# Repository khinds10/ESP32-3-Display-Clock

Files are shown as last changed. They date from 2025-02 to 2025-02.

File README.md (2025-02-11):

# ESP32 Time and Temperature Display

This project uses an ESP32 microcontroller to display the current time and temperatures on three TM1637 displays. The first display shows the current time in 12-hour format with a blinking colon and PM indicator. The second display shows the indoor temperature from a DHT22 sensor. The third display shows the outdoor temperature fetched from an online weather API.

Using openweather API - https://openweathermap.org/api/one-call-3

## Hardware Setup

### Components Required

- 1 x ESP32 Development Board
- 3 x TM1637 4-Digit 7-Segment Displays
- 1 x DHT22 Temperature and Humidity Sensor
- Jumper wires
- 5mm Tinted Plexiglas

### Wiring Diagram

#### TM1637 Displays

- **Display 1 (Time)**
  - CLK1: GPIO 22
  - DIO1: GPIO 23

- **Display 2 (Indoor Temperature)**
  - CLK2: GPIO 19
  - DIO2: GPIO 21

- **Display 3 (Outdoor Temperature)**
  - CLK3: GPIO 32
  - DIO3: GPIO 25

#### DHT22 Sensor

- VCC: 3.3V or 5V
- GND: Ground
- Data: GPIO 18

### Notes

- Ensure all components share a common ground with the ESP32.

## Software Setup

### Prerequisites

- [PlatformIO](https://platformio.org/) installed on your development environment.
- An internet connection for the ESP32 to fetch weather data.

### Check out the Git Repository
https://github.com/khinds10/ESP32-3-Display-Clock
This includes the STL files for 3D printing as well as the code to upload to the ESP32 to get it to run.

### Configuration

1. **Copy Configuration File**

   Copy `src/config_shadow.h` to `src/config.h` and update the configuration values:

   ```bash
   cp src/config_shadow.h src/config.h
   ```

2. **Edit `config.h`**

   Update the following configuration values in `src/config.h`:

   #### Time Settings
   ```cpp
   #define TIME_ZONE -5        // Your timezone offset from UTC (e.g., -5 for EST)
   #define DST_OFFSET 1        // Daylight Saving Time offset (1 for DST, 0 for no DST)
   ```

   #### Display Brightness (0-7)
   ```cpp
   #define TIME_DISPLAY_BRIGHTNESS 3     // Brightness for time display
   #define INSIDE_TEMP_BRIGHTNESS 1      // Brightness for indoor temperature display
   #define OUTSIDE_TEMP_BRIGHTNESS 1     // Brightness for outdoor temperature display
   ```

   #### Temperature Calibration
   ```cpp
   #define TEMP_OFFSET 0.0     // Temperature offset in degrees (adjust if sensor readings need calibration)
   ```

   #### WiFi Settings
   ```cpp
   const char* ssid = "Your_WiFi_SSID";
   const char* password = "Your_WiFi_Password";
   ```

   #### Data Services Configuration
   ```cpp
   // DataHub API endpoint
   const char* datahub_host = "https://your.datahub.endpoint";

   // Weather API settings
   const char* weather_api_endpoint = "https://your.weather.api.endpoint";
   const char* device_name = "your-device-name";
   const char* zipcode = "your-zipcode";

   // Location coordinates (for weather data)
   float latitude = YOUR_LATITUDE;    // e.g., 40.7128
   float longitude = YOUR_LONGITUDE;  // e.g., -74.0060
   ```
   
Create an account on openweathermap.org to get the right weather data for outside conditions.

The API call being used is: https://openweathermap.org/api/one-call-3

Note: Data API is optional

It's built from the following project:

https://github.com/khinds10/DeviceHub

   #### Update Intervals
   ```cpp
   // Weather updates
   const unsigned long WEATHER_UPDATE_INTERVAL = 60000; // Weather update interval in milliseconds

   // Loop manager settings
   const int API_UPDATE_INTERVAL = 600;     // Update API every 600 samples (10 minutes)
   const int RESTART_THRESHOLD = 1800;    // Restart after 1800 samples (30 minutes)
   ```

   These settings control how often the device:
   - Fetches new weather data (WEATHER_UPDATE_INTERVAL)
   - Sends data to your API endpoint (API_UPDATE_INTERVAL)
   - Automatically restarts to prevent memory issues (RESTART_THRESHOLD)

2. **Pin Configuration**

   The default pin configuration is set up for common ESP32 boards. If you need to change the pin assignments, modify these values:

   ```cpp
   // Display pins
   #define CLK1 22    // Time display clock
   #define DIO1 23    // Time display data
   #define CLK2 19    // Indoor temperature display clock
   #define DIO2 21    // Indoor temperature display data
   #define CLK3 32    // Outdoor temperature display clock
   #define DIO3 25    // Outdoor temperature display data

   // Temperature sensor pin
   #define DHTPIN 18  // DHT22 data pin
   ```

### Building and Uploading

1. Connect your ESP32 to your computer via USB.
2. Open the project in your PlatformIO environment.
3. Build and upload the firmware to the ESP32.

## Build Process

Using the 3DPrint/ folder 3D print the STL files to create the case for the project.

Mount the Displays using hot glue to the front panel, also cut and hot glue the Plexiglas (the case allows for 5mm thick glass)

Carefully close the case using the inner-box going inside the larger outer frame. It should snap close with friction.

### Construction Photos

Wiring the displays
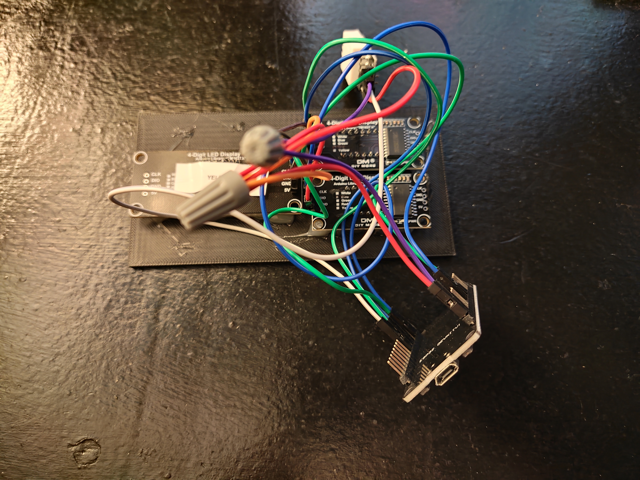
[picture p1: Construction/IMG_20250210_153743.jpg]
Wiring the displays


Mount the displays
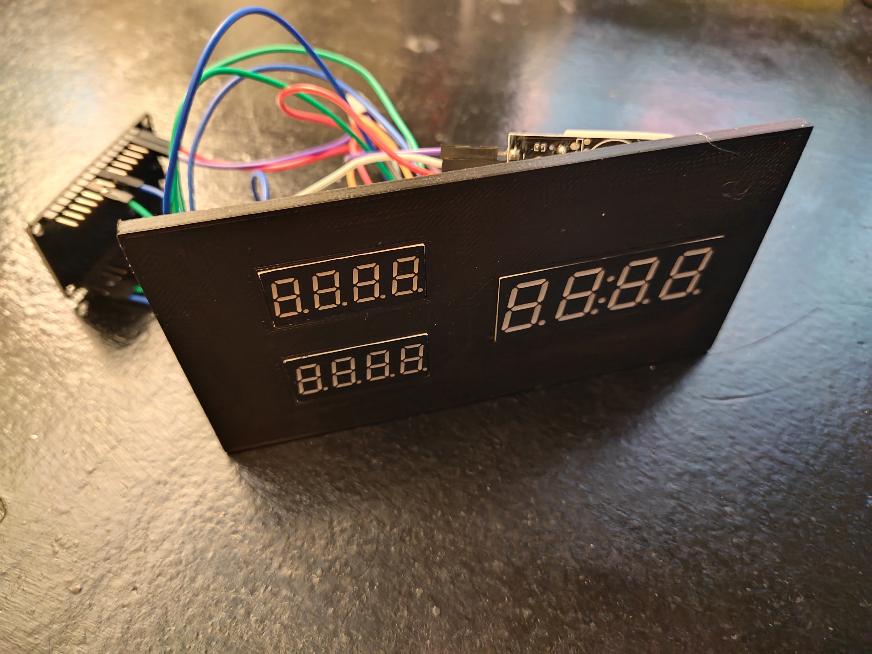
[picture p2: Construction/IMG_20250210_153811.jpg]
Mount the displays


Prepare the 3D Printed Case
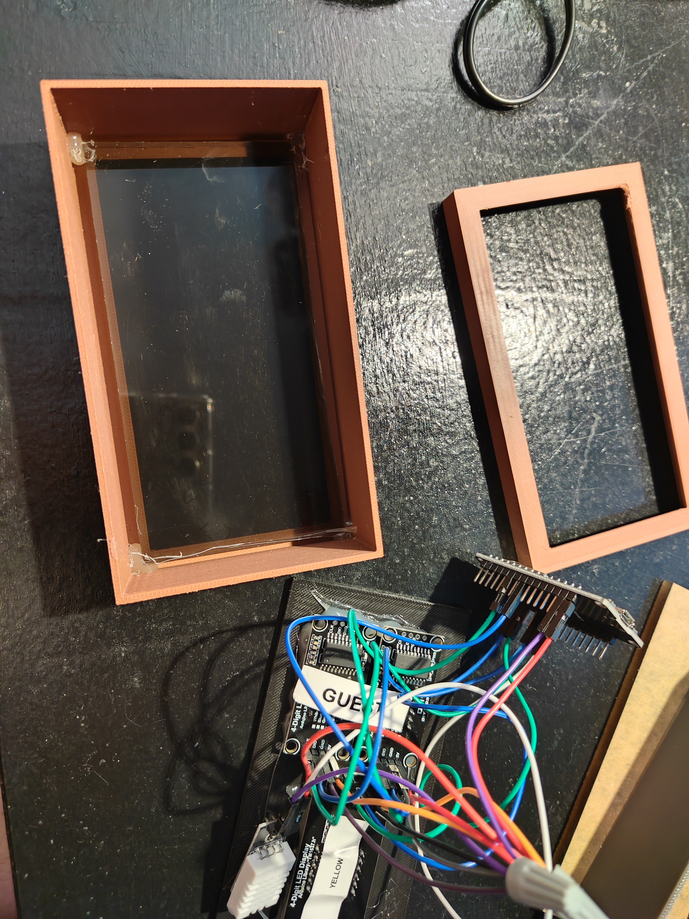
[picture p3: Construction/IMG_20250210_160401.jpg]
Prepare the 3D Printed Case


Assemble the case
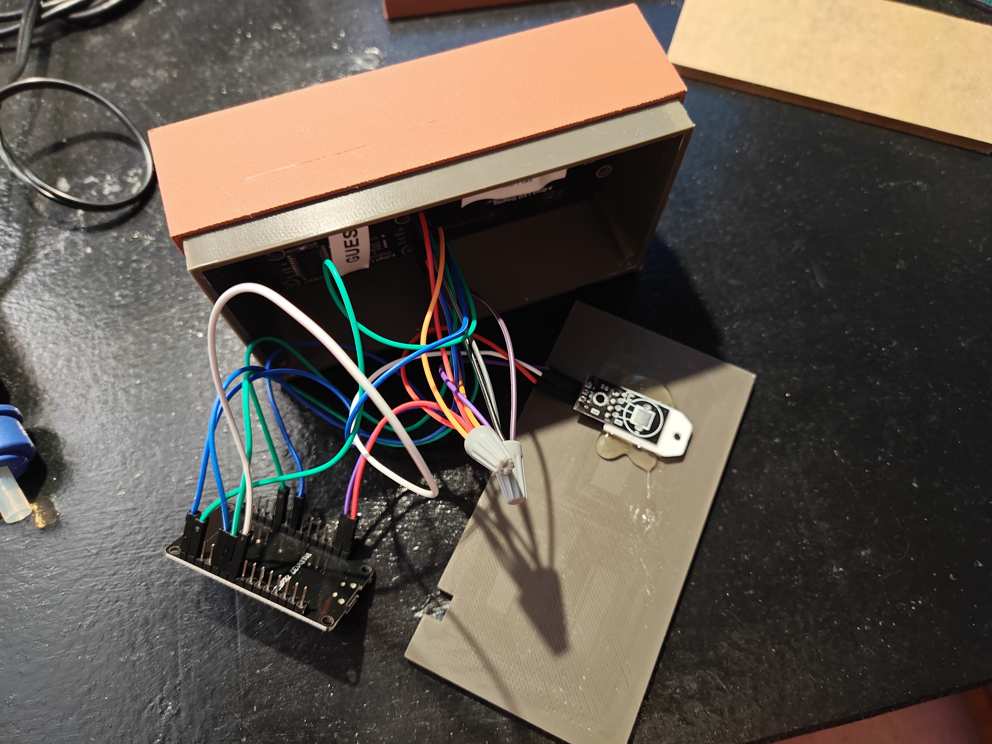
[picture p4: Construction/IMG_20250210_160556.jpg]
Assemble the case


Close up of the assembled case
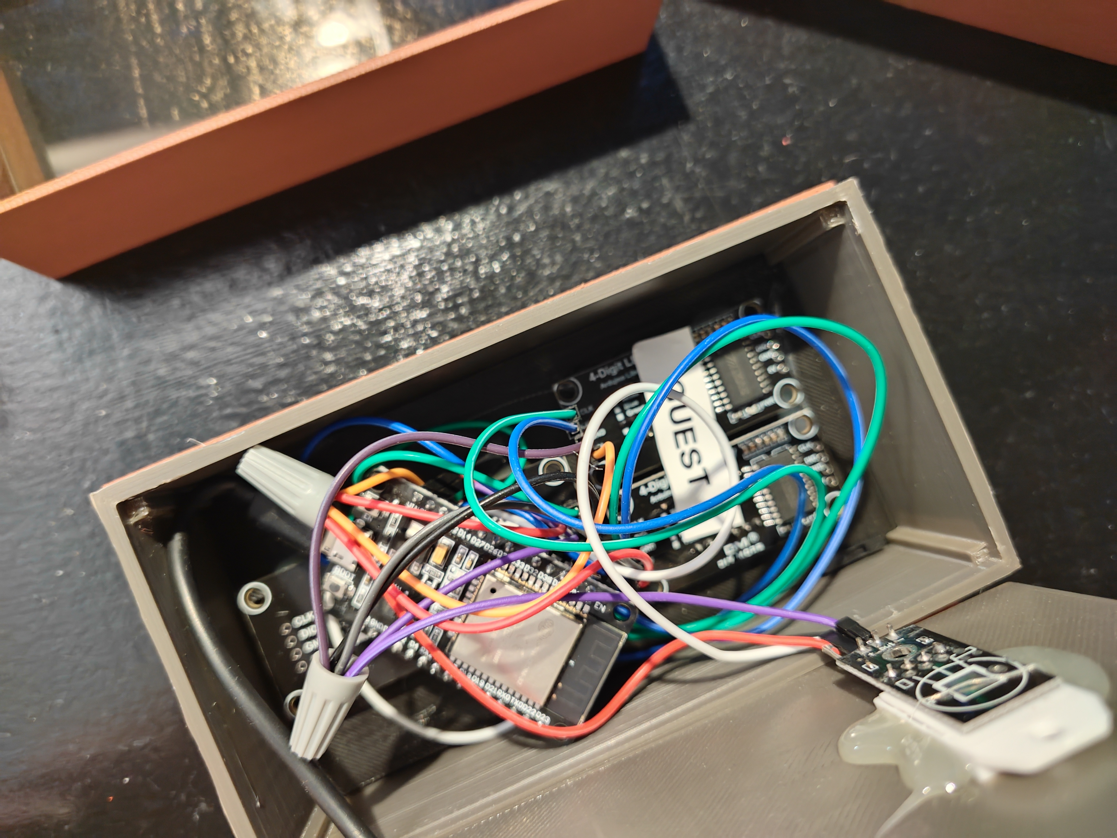
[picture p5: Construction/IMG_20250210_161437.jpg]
Close up of the assembled case


### Finished Product

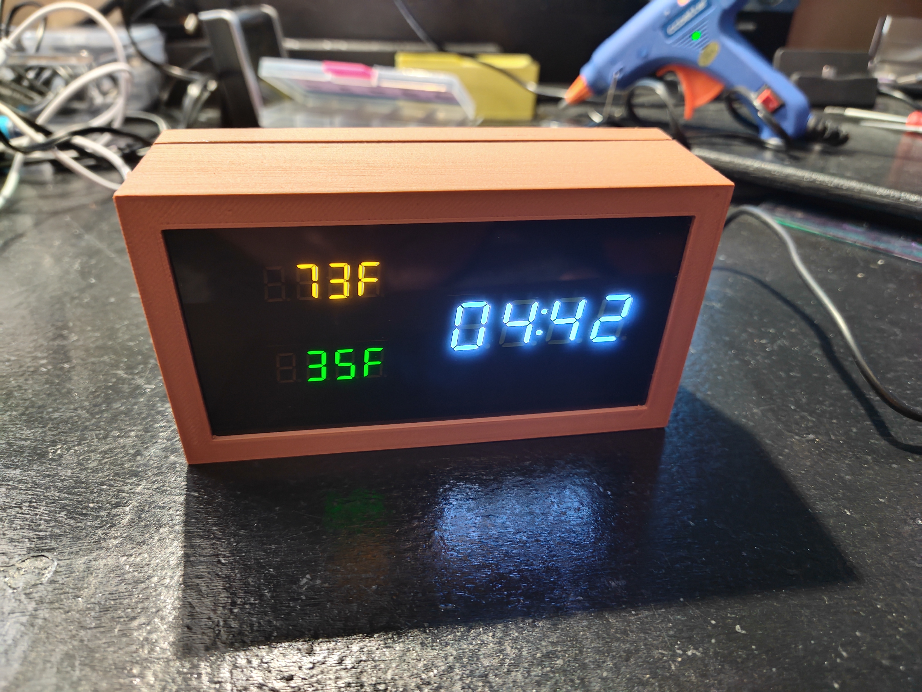
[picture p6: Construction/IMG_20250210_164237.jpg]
Complete setup - front view

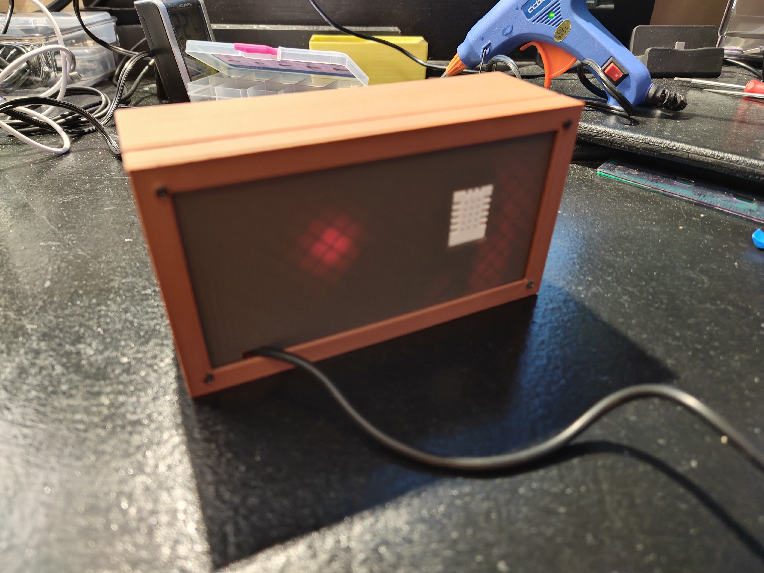
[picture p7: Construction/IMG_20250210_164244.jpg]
Complete setup - rear view

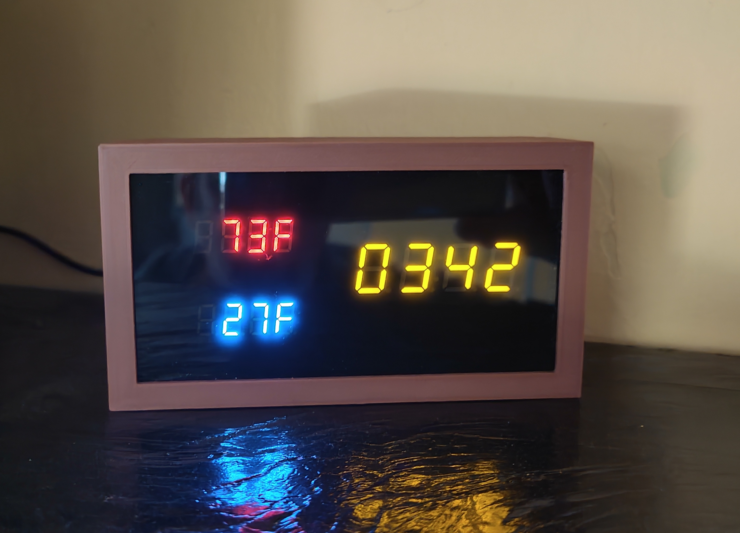
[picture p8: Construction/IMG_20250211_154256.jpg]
Complete setup - in use


### License

This project is licensed under the GNU General Public License v3.0. See the [LICENSE](https://www.gnu.org/licenses/gpl-3.0.en.html) file for details.

### Author

- **Kevin Hinds**
- Website: [www.kevinhinds.com](http://www.kevinhinds.com)
- Date: 2025-01-28 

## GNU General Public License

This program is free software: you can redistribute it and/or modify it under the terms of the GNU General Public License as published by the Free Software Foundation, either version 3 of the License, or (at your option) any later version.

This program is distributed in the hope that it will be useful, but WITHOUT ANY WARRANTY; without even the implied warranty of MERCHANTABILITY or FITNESS FOR A PARTICULAR PURPOSE. See the GNU General Public License for more details.

You should have received a copy of the GNU General Public License along with this program. If not, see [https://www.gnu.org/licenses/](https://www.gnu.org/licenses/).

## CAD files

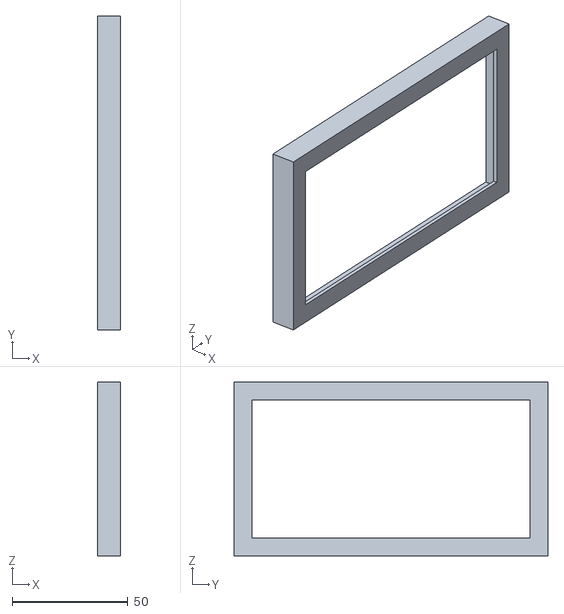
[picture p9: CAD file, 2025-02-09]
3DPrint/STL/frame-new.stl
10.0 x 135.5 x 75.0

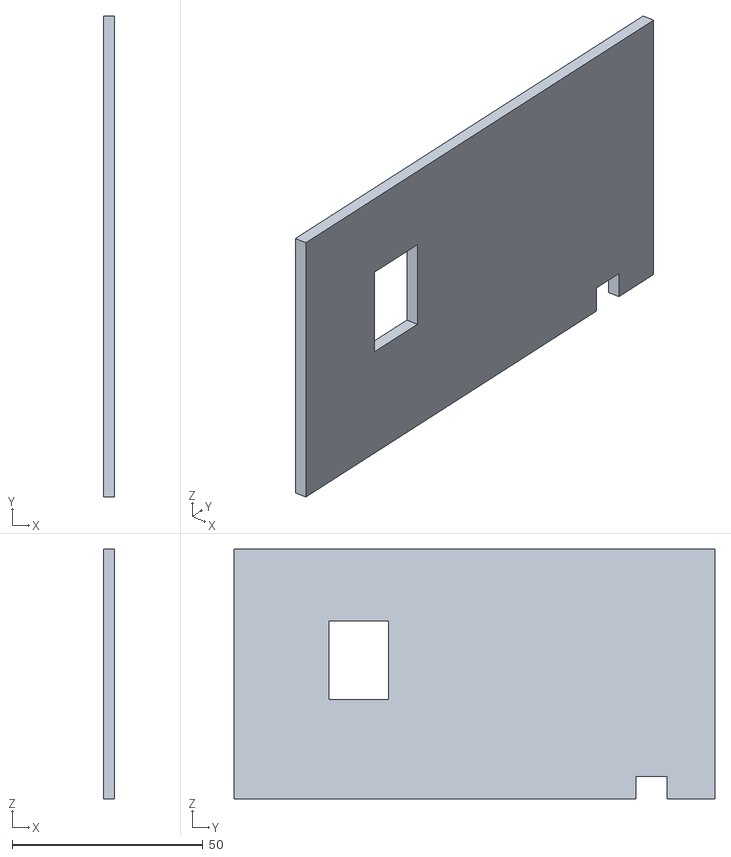
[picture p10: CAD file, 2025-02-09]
3DPrint/STL/back-panel.stl
3.00 x 126.0 x 65.5

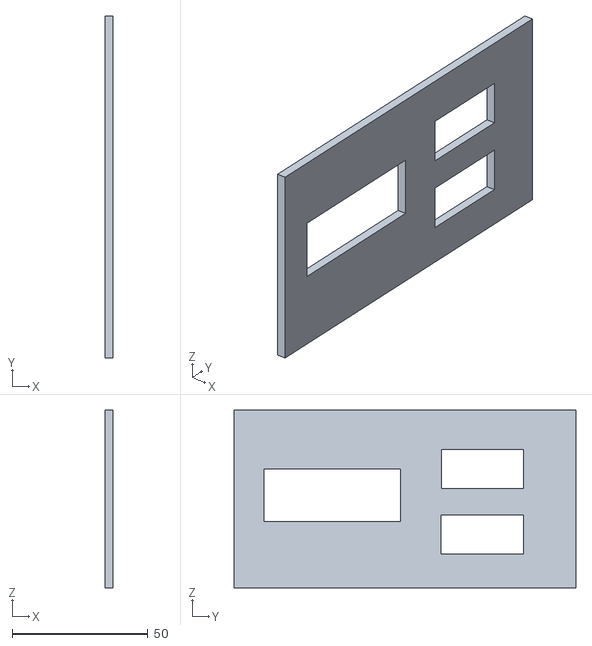
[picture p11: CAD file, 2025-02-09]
3DPrint/STL/front-panel.stl
3.00 x 126.0 x 65.5

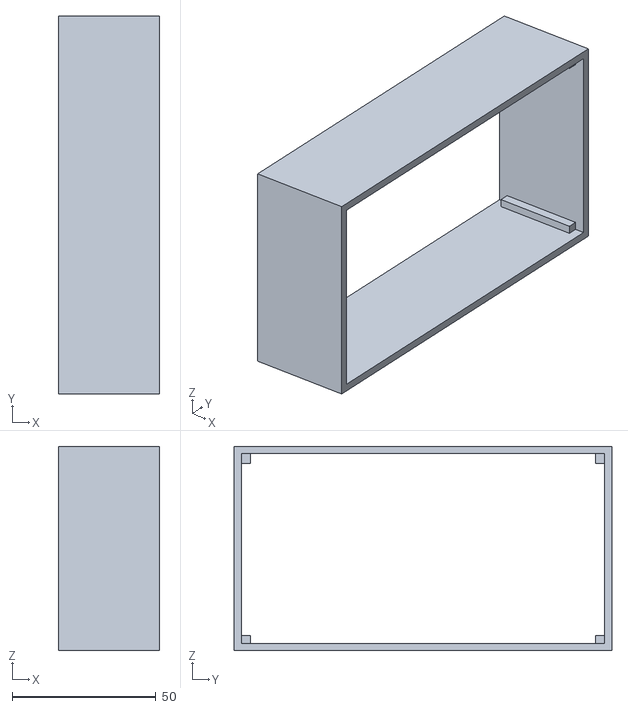
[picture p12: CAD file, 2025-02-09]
3DPrint/STL/box.stl
35.0 x 131.5 x 71.0

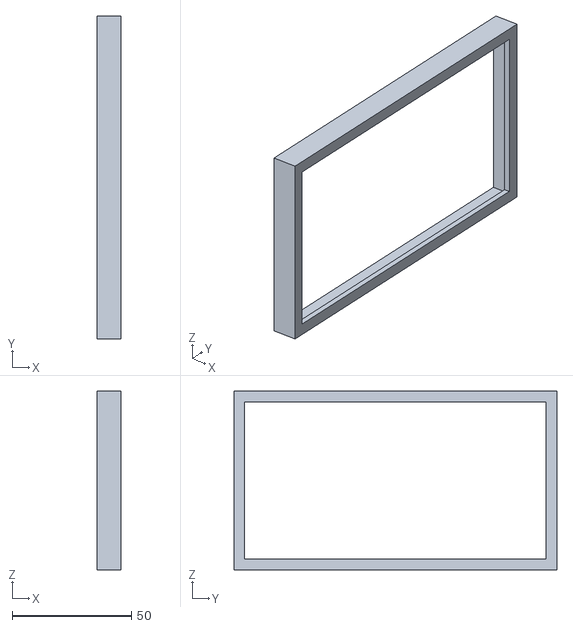
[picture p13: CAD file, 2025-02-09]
3DPrint/STL/testing-frame.stl
10.0 x 135.5 x 75.0

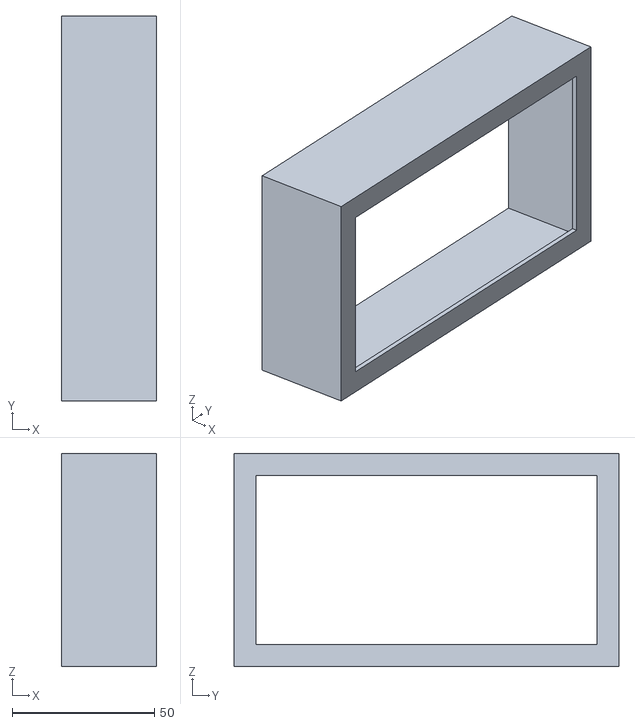
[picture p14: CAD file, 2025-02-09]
3DPrint/STL/frame-large.stl
33.5 x 135.5 x 75.0

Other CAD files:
3DPrint/clock.blend

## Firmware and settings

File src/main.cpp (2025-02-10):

/**
 * Time and Temperature Display Program
 *
 * This program is designed to run on an ESP32 microcontroller. It connects to a WiFi network,
 * fetches the current time and weather data, and displays the time and temperatures on three
 * TM1637 displays. The first display shows the current time in 12-hour format with a blinking
 * colon and PM indicator. The second display shows the indoor temperature from a DHT22 sensor.
 * The third display shows the outdoor temperature fetched from an online weather API.
 *
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
 * Author: Kevin Hinds
 * Date: 2025-01-28
 * Website: www.kevinhinds.com
 */

#include <Adafruit_Sensor.h>
#include <Arduino.h>
#include <ArduinoJson.h>
#include "config.h"
#include <string>
#include <time.h>
#include <WiFi.h>
#include <Wire.h>
#include <HTTPClient.h>

// include internet files
#include <internet/api.h>
#include <internet/wifi.h>

// include device files
#include <DHT.h>
#include <DHT_U.h>
#include <devices/dht22.h>
#include <devices/LoopManager.h>

// include display files
#include <TM1637Display.h>
#include <devices/TM1637.h>

// Create objects
ExtendedTM1637Display timeDisplay(CLK1, DIO1);        // time display
ExtendedTM1637Display insideTempDisplay(CLK2, DIO2);  // inside temp display
ExtendedTM1637Display outsideTempDisplay(CLK3, DIO3); // outside temp display

// DHT22 sensor
ExtendedDHT22 dht(DHTPIN, DHTTYPE);

// API
API api;

// WiFi
ExtendedWiFi wifi(ssid, password);

// LoopManager for API incremental updates and restart thresholds
LoopManager loopManager;

void setup() {
  Serial.begin(115200);

  // begin WiFi connection
  wifi.init();
  Serial.print("RSSI: ");
  Serial.println(wifi.getRSSI());

  // init and get the time
  configTime(gmtOffset_sec, daylightOffset_sec, ntpServer);

  // time display
  timeDisplay.setBrightness(TIME_DISPLAY_BRIGHTNESS);
  timeDisplay.clear();

  // inside temp display
  insideTempDisplay.setBrightness(INSIDE_TEMP_BRIGHTNESS);
  insideTempDisplay.clear();

  // outside temp display
  outsideTempDisplay.setBrightness(OUTSIDE_TEMP_BRIGHTNESS);
  outsideTempDisplay.clear();

  // Get initial outside temperature reading
  dht.begin();
  String outsideTemp = api.updateWeatherHub(dht.getTemperatureF(), dht.getHumidity());
  outsideTempDisplay.showTemperature(outsideTemp);
}

void loop() {

    loopManager.increment();
    Serial.println("Samples taken: " + String(loopManager.getSamplesTaken()));
    Serial.println("Total samples: " + String(loopManager.getTotalSamples()));

    // Get current time
    time_t now = time(nullptr);
    struct tm *timeInfo = localtime(&now);
    timeDisplay.updateTimeDisplay(timeInfo);

    // Display inside temperature
    insideTempDisplay.showTemperature(dht.getTemperatureF());

    // Update the weather hub, data hub, and outside temperature display
    if (loopManager.shouldUpdateAPI()) {
        String outsideTemp = api.updateWeatherHub(dht.getTemperatureF(), dht.getHumidity());
        outsideTempDisplay.showTemperature(outsideTemp);
        loopManager.resetSamplesTaken();
    }

    // Restart the ESP32
    if (loopManager.shouldRestart()) ESP.restart();
    delay(1000);
}

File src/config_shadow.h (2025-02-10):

#ifndef CONFIG_H
#define CONFIG_H

// Add timezone
#define TIME_ZONE -5 // EST (UTC-5)
#define DST_OFFSET 1 // Add 1 hour during DST

// Display brightness settings (0-7)
#define TIME_DISPLAY_BRIGHTNESS 3
#define INSIDE_TEMP_BRIGHTNESS 1
#define OUTSIDE_TEMP_BRIGHTNESS 1

// First display
#define CLK1 22 // First display CLK
#define DIO1 23 // First display DIO

// Second display
#define CLK2 19 // Second display CLK
#define DIO2 21 // Second display DIO

// Third display
#define CLK3 32 // Third display CLK
#define DIO3 25 // Third display DIO

// DHT22 pin
#define DHTPIN 18
#define DHTTYPE DHT22

// Add temperature offset correction
#define TEMP_OFFSET 0.0 // Add 3 degrees to compensate for sensor

// WiFi credentials
const char* ssid = "LINKSYS";
const char* password = "password";
char date_string[100];

// // NTP setup
const char* ntpServer = "north-america.pool.ntp.org";
const long  gmtOffset_sec = -18000; // Eastern Daylight Time (EDT)
const int   daylightOffset_sec = 3600;

// scheduled datahub config
const char* datahub_host = "https://devices.website.net";

// weather api endpoint
const char* weather_api_endpoint = "https://openweather.website.net/";
const char* device_name = "temp-check-default";
const char* zipcode = "10001";

// latitude and logitude
float latitude = 40.0;
float longitude = -70.0;

// Update intervals
const unsigned long WEATHER_UPDATE_INTERVAL = 60000; // 60 seconds

// Loop manager configuration
const int API_UPDATE_INTERVAL = 600;    // Update API every 600 samples (10 minutes)
const int RESTART_THRESHOLD = 1800;    // Restart after 1800 samples (30 minutes)

#endif // CONFIG_H 

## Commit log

2025-02-09 initial project;
    [back-panel.stl, box.stl, clock.blend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]
2025-02-10 sample and reset times configurable
    [config_shadow.h, main.cpp]
